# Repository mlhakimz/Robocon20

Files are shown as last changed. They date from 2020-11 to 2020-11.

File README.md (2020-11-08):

# Robocon20
2 Co-op robots playing Rugby 7s based on Fiji's Robocon 2020 theme.

## Mechanical Design

PASS ROBOT

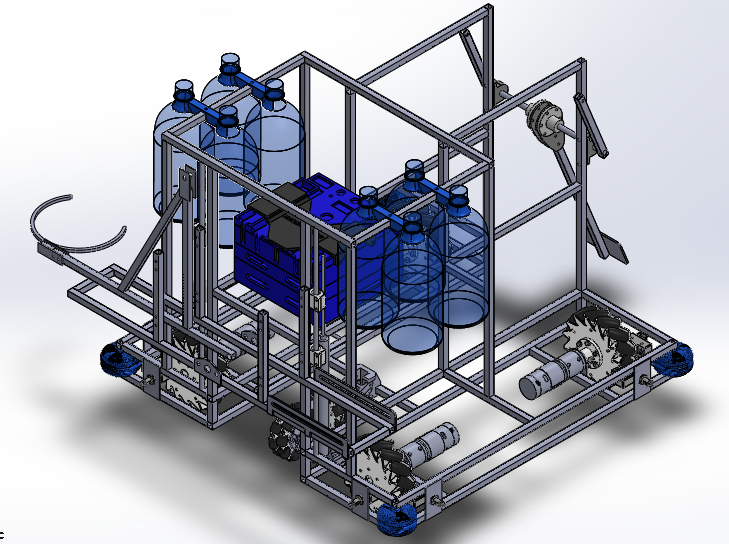
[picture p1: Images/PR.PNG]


TRY ROBOT

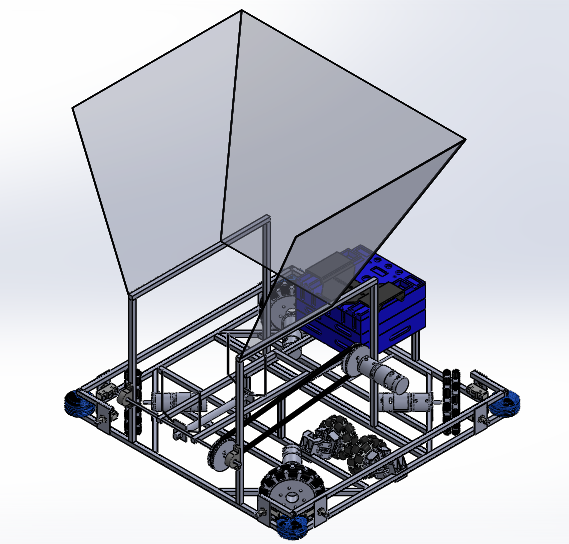
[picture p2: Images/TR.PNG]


## Electronics Design

PCB BOARD

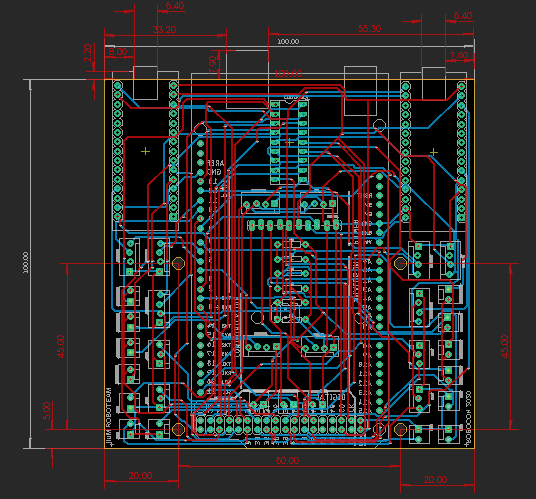
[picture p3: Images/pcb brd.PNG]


PCB SCHEMATIC

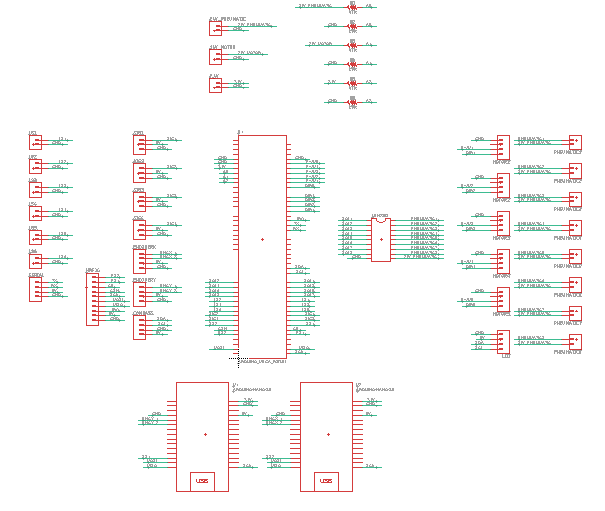
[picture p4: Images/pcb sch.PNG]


ARDUINO MEGA CONNECTIONS

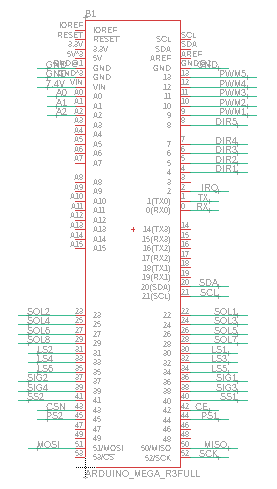
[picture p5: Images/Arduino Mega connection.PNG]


ARDUINO NANO CONNECTIONS

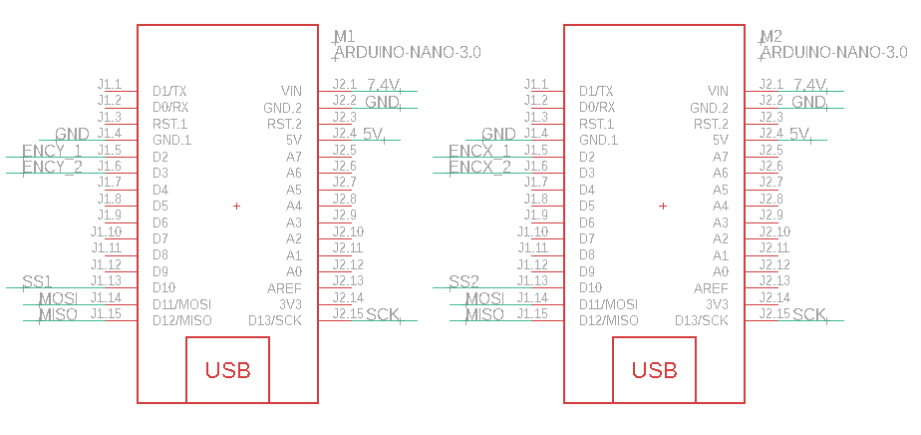
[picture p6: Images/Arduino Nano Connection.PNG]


INPUT PORTS

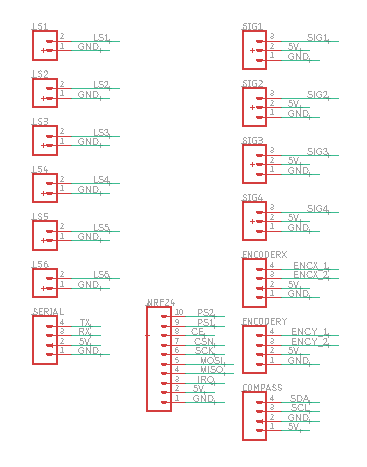
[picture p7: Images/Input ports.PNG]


OUTPUT PORTS

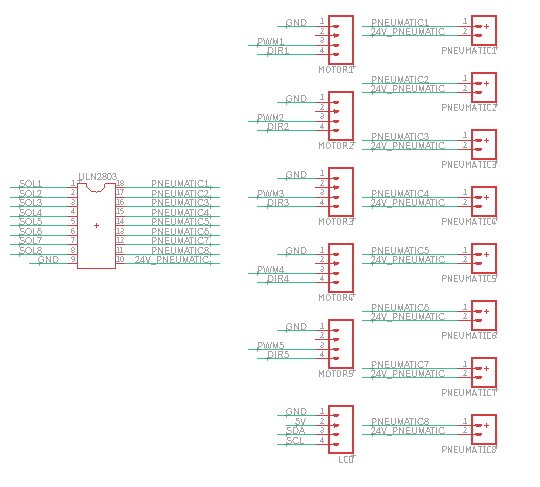
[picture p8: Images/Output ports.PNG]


VOLTMETER CONNECTION

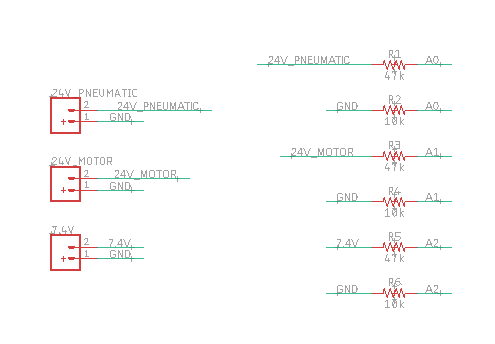
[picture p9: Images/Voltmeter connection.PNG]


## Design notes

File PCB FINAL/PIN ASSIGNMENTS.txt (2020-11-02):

2     - IRQ
4-8   - DIR
9-13  - PWM
20-21 - SDA SCL
22-29 - SOL (PNEUMATIC)
30-35 - LIMIT SWITCH
36-39 - DIGITAL INPUT (IR SENSOR)
50-52 - MISO MOSI SCK
40-41 - SLAVE SELECT
42-43 - CE CSN
A0-A2 - VOLTMETER

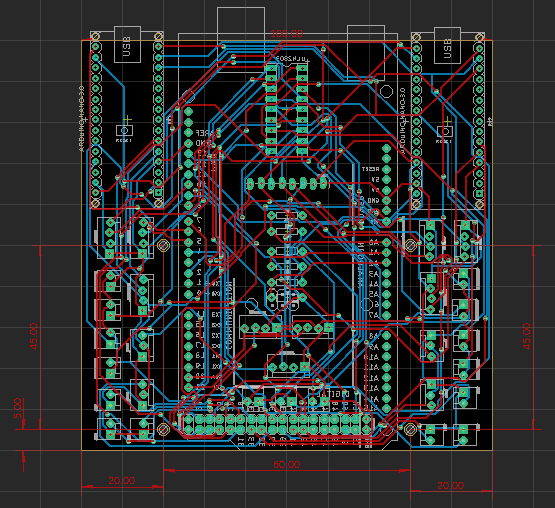
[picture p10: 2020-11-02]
PCB FINAL/PCB FINAL.PNG

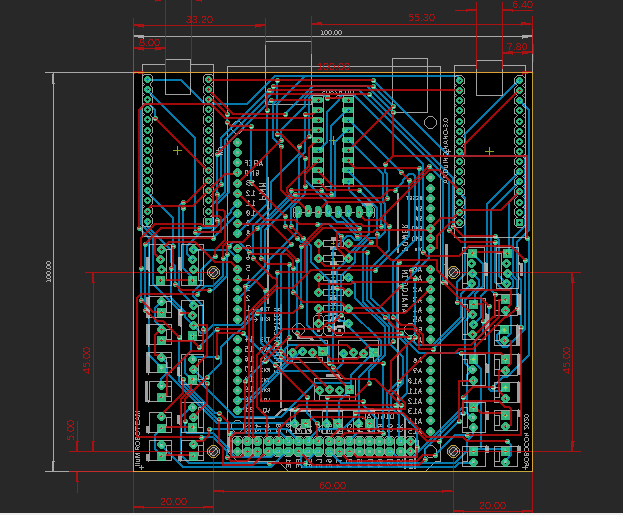
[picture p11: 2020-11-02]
PCB FINAL/PCB UPDATED.PNG

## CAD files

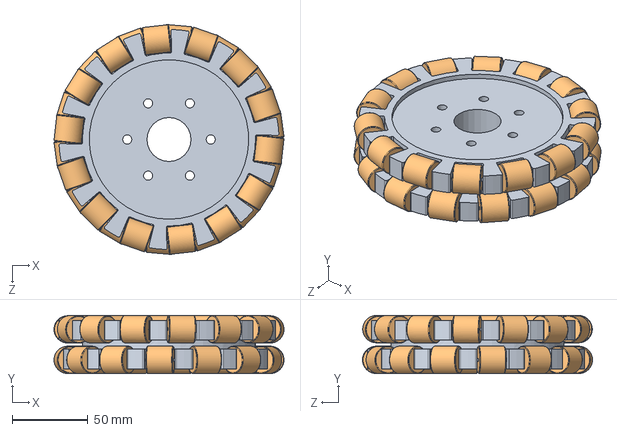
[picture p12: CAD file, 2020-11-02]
TR v2/Omni Wheel 152mm.SLDASM
151.5 x 38.3 x 151.6 mm
WHEEL x 28

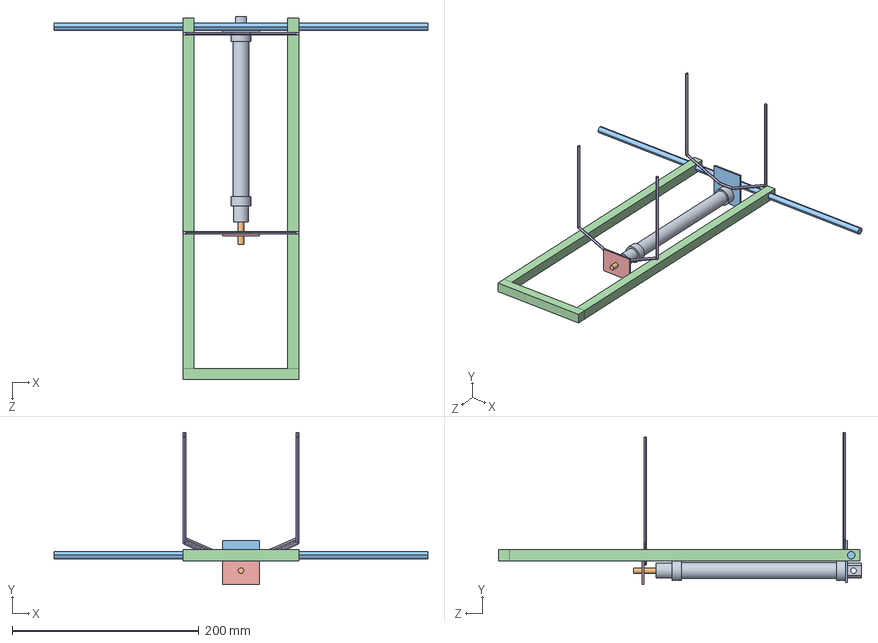
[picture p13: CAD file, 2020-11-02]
TR v2/try_mech.SLDASM
400.0 x 163.0 x 388.7 mm
Pneumatic_Body_125
Pneumatic_Rod_125
Rod_300
Platform_Receive
Plate_Var_Grip
Grip_V2 x 2

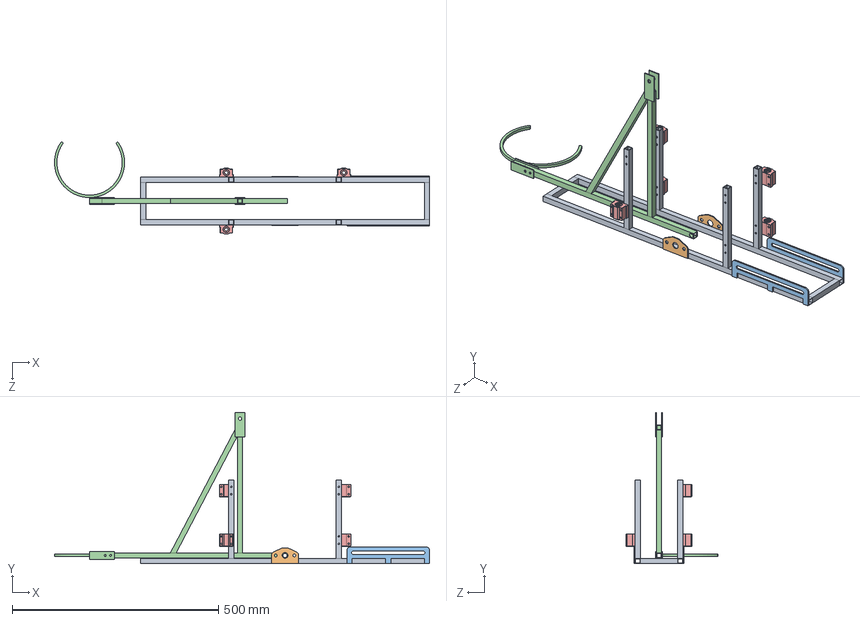
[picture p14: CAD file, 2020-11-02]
PR/Passing Mechanism.SLDASM
908.6 x 366.1 x 222.6 mm
Passing Mechanism Base v2
Bearing Plate x 2
Pneumatic Bottom Slot x 2
Throwing Arm
Linear Bearing 8mm ID x 4

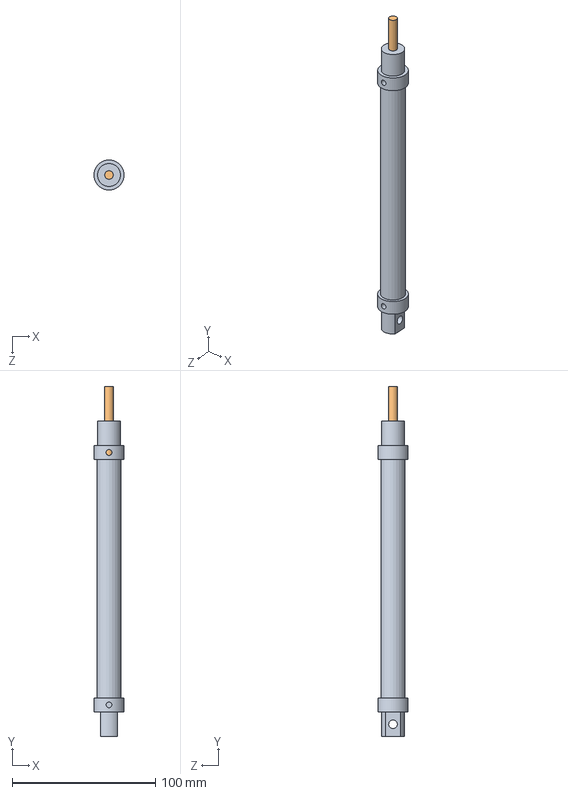
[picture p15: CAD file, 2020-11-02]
TR v2/Pneumatic_125.SLDASM
21.0 x 244.0 x 21.0 mm
Pneumatic_Body_125
Pneumatic_Rod_125

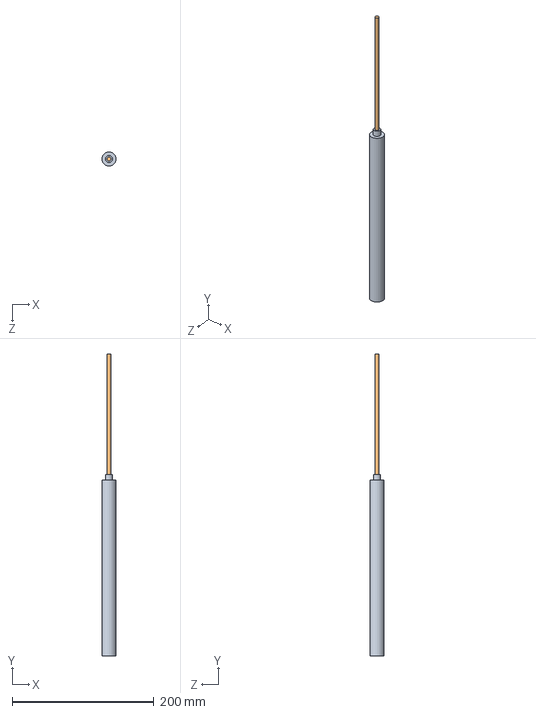
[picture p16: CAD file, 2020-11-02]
PR/Pneumatic16x200.SLDASM
20.0 x 426.1 x 20.0 mm
Pneumatic16x200 body
Pneumatic16x200 piston

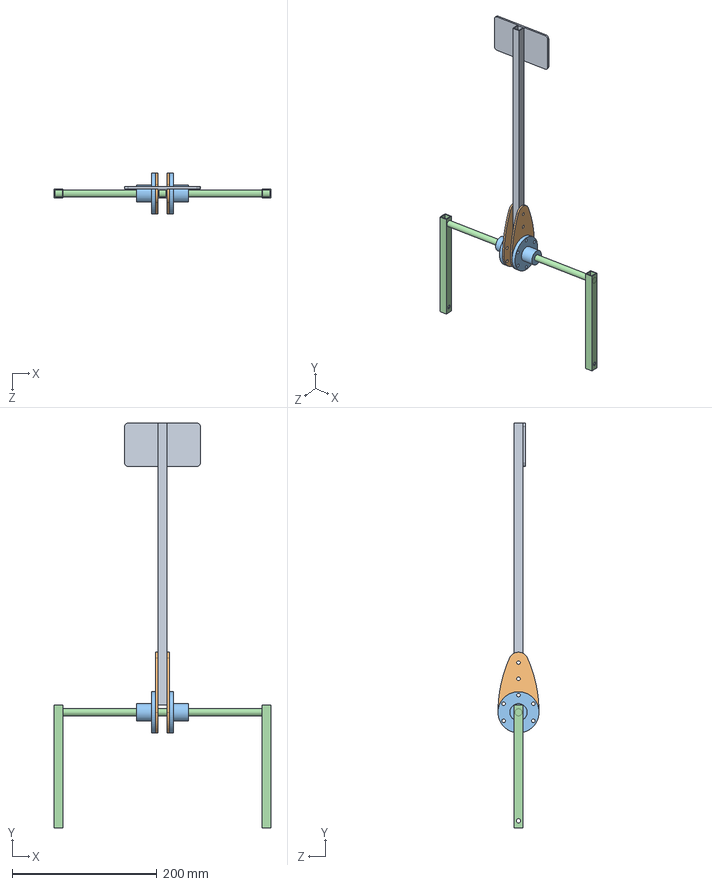
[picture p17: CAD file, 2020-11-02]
PR/Kicking Mechanism.SLDASM
300.0 x 560.0 x 56.8 mm
Kicking Leg
Coupler kicking 10mm x 2
Coupler 10mm x 2
Shaft 10mm diameter 300mm length

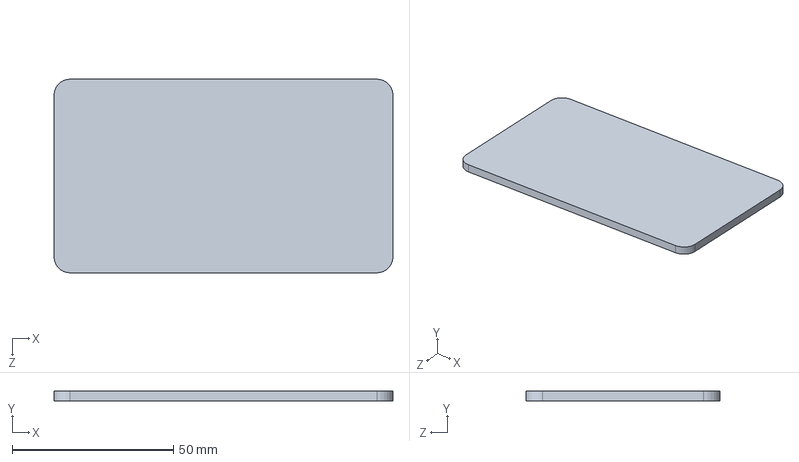
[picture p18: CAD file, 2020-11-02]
PR/Kicking Plate.SLDPRT
105.0 x 3.00 x 60.0 mm

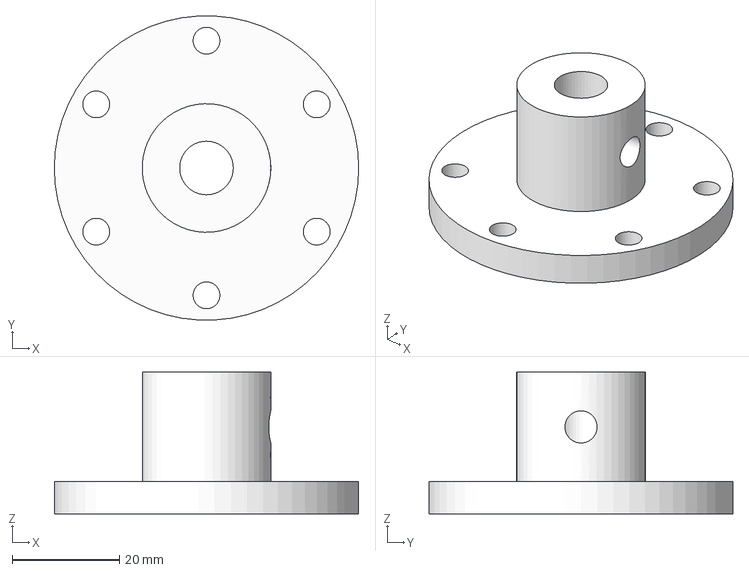
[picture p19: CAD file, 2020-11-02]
PR/Coupler 10mm.step
56.8 x 56.7 x 26.4 mm

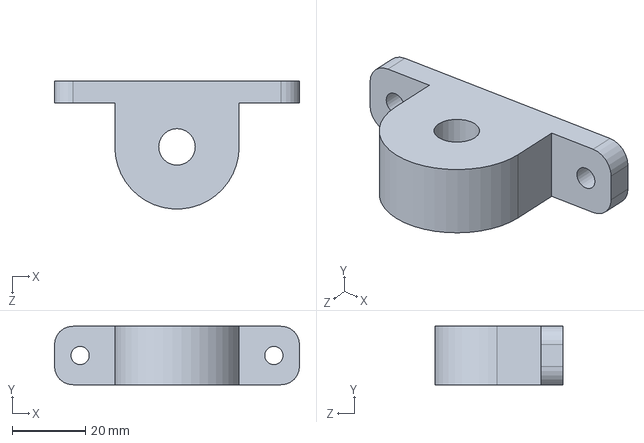
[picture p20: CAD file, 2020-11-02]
PR/Pillow Block Bearing 10mm.SLDPRT
67.0 x 16.0 x 35.0 mm

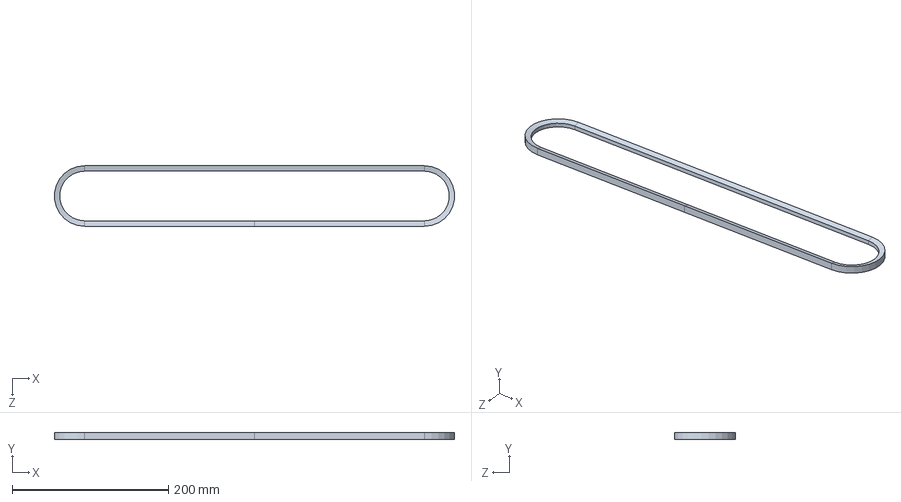
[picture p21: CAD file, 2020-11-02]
TR v2/v belt.SLDPRT
512.3 x 8.75 x 77.5 mm

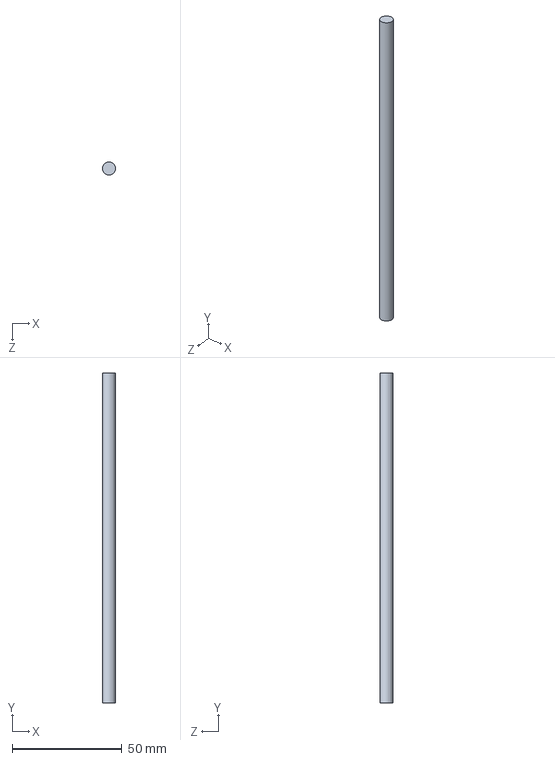
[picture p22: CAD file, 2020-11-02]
TR v2/Pneumatic_Rod_125.SLDPRT
6.00 x 150.0 x 6.00 mm

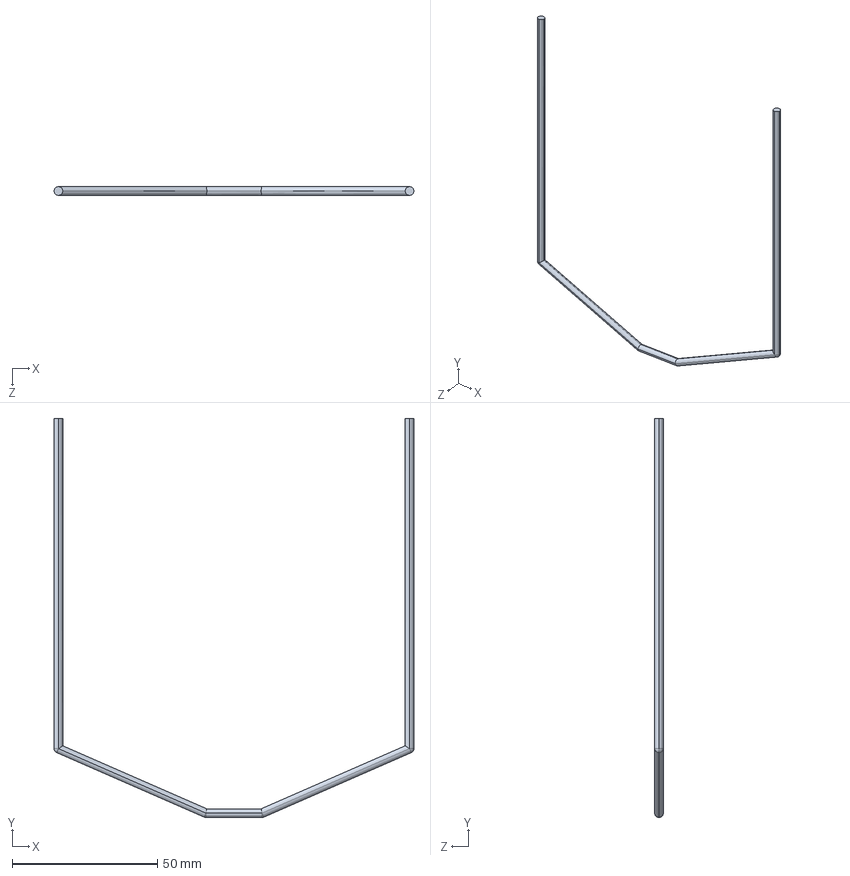
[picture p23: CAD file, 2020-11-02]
TR v2/Grip_V2.SLDPRT
124.0 x 137.5 x 3.00 mm

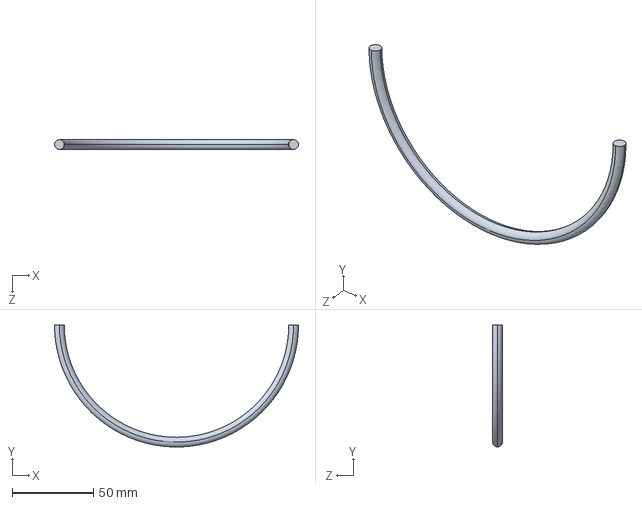
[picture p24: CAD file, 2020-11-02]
TR v2/U_Griper.SLDPRT
150.0 x 74.9 x 6.00 mm

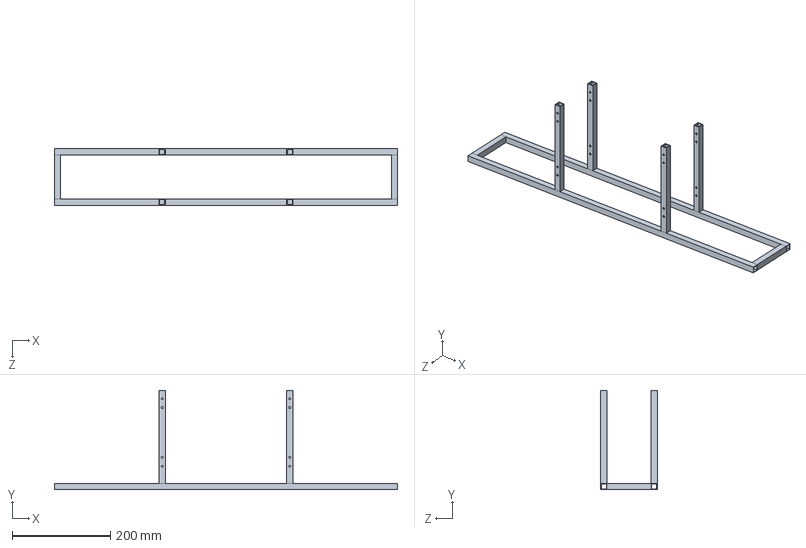
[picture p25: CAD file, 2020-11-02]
PR/Passing Mechanism Base v2.SLDPRT
700.0 x 202.7 x 115.4 mm

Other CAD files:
PR/Mecanum Wheel 6in.sldprt
TR v2/Part4.sldprt
PR/_X_CA_X_EE_X_ED_X_F6_X_E5_X_E2_X_E8_X_EA GQ21-B(Z-15GQ2_2-B) - _X_F8_X_E0_X_E9_X_E1_X_E0_00.sldprt
PR/Coupler kicking 10mm.SLDPRT
PR/4 inch onmiwheel roller.sldprt
PR/90348A024.sldprt
PR/9338T51.sldprt
PR/93625A200.sldprt
PR/Base PR.SLDPRT
PR/Bearing Plate.SLDPRT
PR/Coupler 10mm v3.step
PR/Coupler 10mm.SLDPRT
PR/Kicking Leg.SLDPRT
PR/Linear Bearing 8mm ID.SLDASM
PR/Linear Bearing 8mm ID.SLDPRT
PR/Linear Bearing 8mm ID.step
PR/Passing Mechanism Base.SLDPRT
PR/Pneumatic Bottom Slot.SLDPRT
PR/Pneumatic16x200 body.SLDPRT
PR/Pneumatic16x200 piston.SLDPRT
PR/Shaft 10mm diameter 300mm length.SLDPRT
PR/Throwing Arm.SLDPRT
PR/_X_CA_X_EE_X_ED_X_F6_X_E5_X_E2_X_E8_X_EA GQ21-B(Z-15GQ2_2-B) - _X_E3_X_E0_X_E9_X_EA_X_E0_00.sldprt
PR/_X_CA_X_EE_X_ED_X_F6_X_E5_X_E2_X_E8_X_EA GQ21-B(Z-15GQ2_2-B)_GQ22-B.sldprt
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

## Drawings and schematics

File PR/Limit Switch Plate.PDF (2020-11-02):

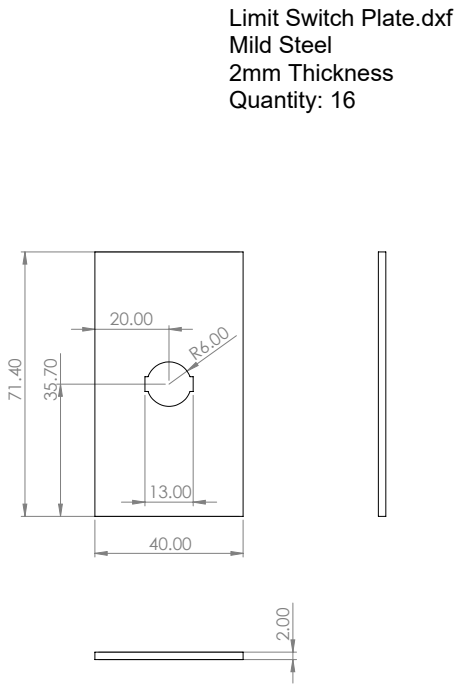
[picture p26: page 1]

Limit Switch Plate.dxf
Mild Steel
2mm Thickness
Quantity: 16

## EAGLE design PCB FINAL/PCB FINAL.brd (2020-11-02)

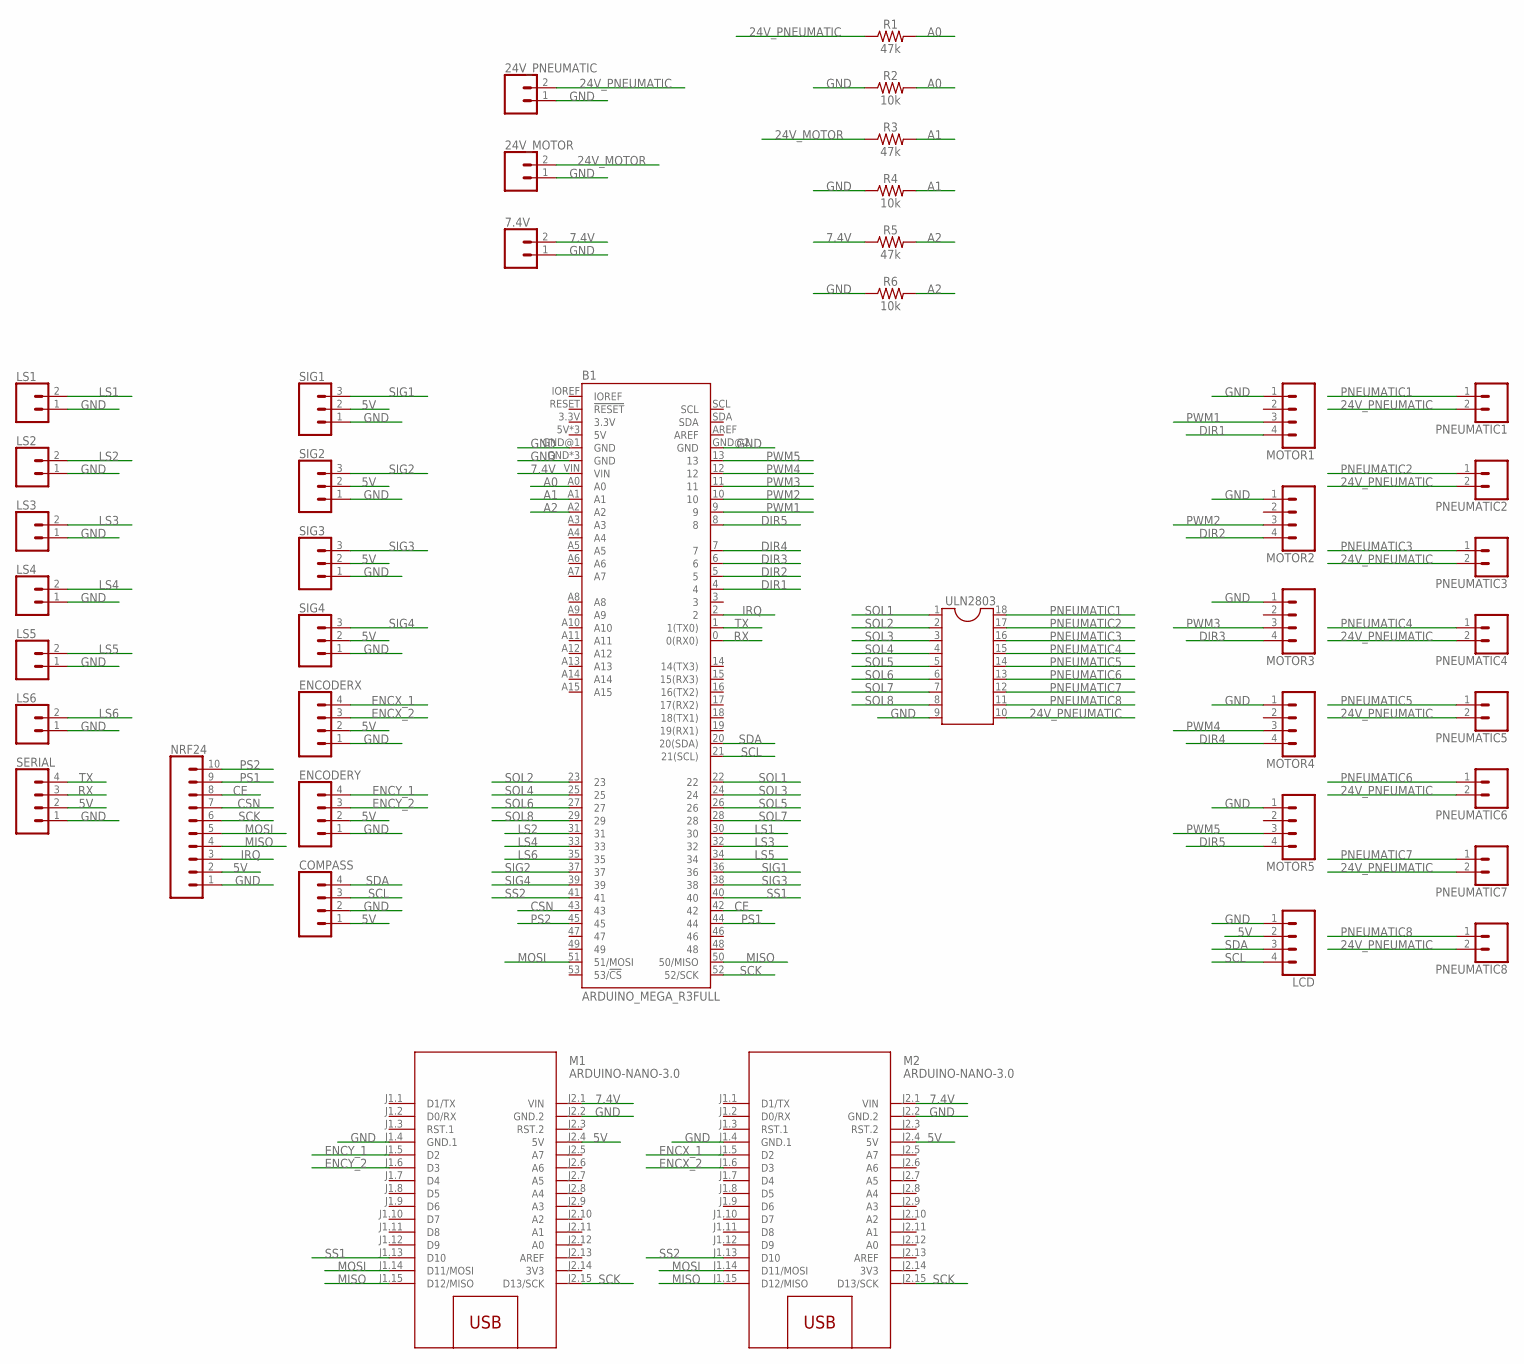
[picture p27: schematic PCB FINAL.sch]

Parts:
7.4V, 24V_MOTOR, 24V_PNEUMATIC: CONN_02POLAR_LOCK; MOLEX-1X2_LOCK
B1: ARDUINO_MEGA_R3FULL; ARDUINO_MEGA_NO_SILK
COMPASS: CONN_04POLAR_LOCK; MOLEX-1X4_LOCK
ENCODERX: CONN_04POLAR_LOCK; MOLEX-1X4_LOCK
ENCODERY: CONN_04POLAR_LOCK; MOLEX-1X4_LOCK
LCD: CONN_04POLAR_LOCK; MOLEX-1X4_LOCK
LS1, LS2, LS3, LS4, LS5, LS6: CONN_02POLAR_LOCK; MOLEX-1X2_LOCK
M1, M2: ARDUINO-NANO-3.0
MOTOR1, MOTOR2, MOTOR3, MOTOR4, MOTOR5: CONN_04POLAR_LOCK; MOLEX-1X4_LOCK
NRF24: CONN_10LOCK_LONGPADS; 1X10_LOCK_LONGPADS
PNEUMATIC1, PNEUMATIC2, PNEUMATIC3, PNEUMATIC4, PNEUMATIC5, PNEUMATIC6, PNEUMATIC7, PNEUMATIC8: CONN_02POLAR_LOCK; MOLEX-1X2_LOCK
R1, R3, R5: 47k; AXIAL-0.3
R2, R4, R6: 10k; AXIAL-0.3
SERIAL: CONN_04POLAR_LOCK; MOLEX-1X4_LOCK
SIG1, SIG2, SIG3, SIG4: CONN_03POLAR_LOCK; MOLEX-1X3_LOCK
ULN2803: DIL18S; SOCKET-18

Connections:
3V3: M1.J2.14 (3V3), M2.J2.14 (3V3)
5V: COMPASS.1, ENCODERX.2, ENCODERY.2, LCD.2, M1.J2.4 (5V), M2.J2.4 (5V), NRF24.2, SERIAL.2, SIG1.2, SIG2.2, SIG3.2, SIG4.2
7.4V: 7.4V.2, B1.VIN, M1.J2.1 (VIN), M2.J2.1 (VIN), R5.P$1 (1)
24V_MOTOR: 24V_MOTOR.2, R3.P$1 (1)
24V_PNEUMATIC: 24V_PNEUMATIC.2, PNEUMATIC1.2, PNEUMATIC2.2, PNEUMATIC3.2, PNEUMATIC4.2, PNEUMATIC5.2, PNEUMATIC6.2, PNEUMATIC7.2, PNEUMATIC8.2, R1.P$1 (1), ULN2803.10
A0: B1.A0, R1.P$2 (2), R2.P$2 (2)
A1: B1.A1, R3.P$2 (2), R4.P$2 (2)
A2: B1.A2, R5.P$2 (2), R6.P$2 (2)
CE: B1.42, NRF24.8
CSN: B1.43, NRF24.7
DIR1: B1.4, MOTOR1.4
DIR2: B1.5, MOTOR2.4
DIR3: B1.6, MOTOR3.4
DIR4: B1.7, MOTOR4.4
DIR5: B1.8, MOTOR5.4
ENCX_1: ENCODERX.4, M2.J1.5 (D2)
ENCX_2: ENCODERX.3, M2.J1.6 (D3)
ENCY_1: ENCODERY.4, M1.J1.5 (D2)
ENCY_2: ENCODERY.3, M1.J1.6 (D3)
GND: 7.4V.1, 24V_MOTOR.1, 24V_PNEUMATIC.1, B1.GND, B1.GND@1 (GND), B1.GND@2 (GND), B1.GND@3 (GND), B1.GND@4 (GND), COMPASS.2, ENCODERX.1, ENCODERY.1, LCD.1, LS1.1, LS2.1, LS3.1, LS4.1, LS5.1, LS6.1, M1.J1.4 (GND.1), M1.J2.2 (GND.2), M2.J1.4 (GND.1), M2.J2.2 (GND.2), MOTOR1.1, MOTOR2.1, MOTOR3.1, MOTOR4.1, MOTOR5.1, NRF24.1, R2.P$1 (1), R4.P$1 (1), R6.P$1 (1), SERIAL.1, SIG1.1, SIG2.1, SIG3.1, SIG4.1, ULN2803.9
IRQ: B1.2, NRF24.3
LS1: B1.30, LS1.2
LS2: B1.31, LS2.2
LS3: B1.32, LS3.2
LS4: B1.33, LS4.2
LS5: B1.34, LS5.2
LS6: B1.35, LS6.2
MISO: B1.50 (50/MISO), M1.J1.15 (D12/MISO), M2.J1.15 (D12/MISO), NRF24.4
MOSI: B1.51 (51/MOSI), M1.J1.14 (D11/MOSI), M2.J1.14 (D11/MOSI), NRF24.5
PNEUMATIC1: PNEUMATIC1.1, ULN2803.18
PNEUMATIC2: PNEUMATIC2.1, ULN2803.17
PNEUMATIC3: PNEUMATIC3.1, ULN2803.16
PNEUMATIC4: PNEUMATIC4.1, ULN2803.15
PNEUMATIC5: PNEUMATIC5.1, ULN2803.14
PNEUMATIC6: PNEUMATIC6.1, ULN2803.13
PNEUMATIC7: PNEUMATIC7.1, ULN2803.12
PNEUMATIC8: PNEUMATIC8.1, ULN2803.11
PS1: B1.44, NRF24.9
PS2: B1.45, NRF24.10
PWM1: B1.9, MOTOR1.3
PWM2: B1.10, MOTOR2.3
PWM3: B1.11, MOTOR3.3
PWM4: B1.12, MOTOR4.3
PWM5: B1.13, MOTOR5.3
RX: B1.0 (0(RX0)), SERIAL.3
SCK: B1.52 (52/SCK), M1.J2.15 (D13/SCK), M2.J2.15 (D13/SCK), NRF24.6
SCL: B1.21 (21(SCL)), COMPASS.3, LCD.4
SDA: B1.20 (20(SDA)), COMPASS.4, LCD.3
SIG1: B1.36, SIG1.3
SIG2: B1.37, SIG2.3
SIG3: B1.38, SIG3.3
SIG4: B1.39, SIG4.3
SOL1: B1.22, ULN2803.1
SOL2: B1.23, ULN2803.2
SOL3: B1.24, ULN2803.3
SOL4: B1.25, ULN2803.4
SOL5: B1.26, ULN2803.5
SOL6: B1.27, ULN2803.6
SOL7: B1.28, ULN2803.7
SOL8: B1.29, ULN2803.8
SS1: B1.40, M1.J1.13 (D10)
SS2: B1.41, M2.J1.13 (D10)
TX: B1.1 (1(TX0)), SERIAL.4

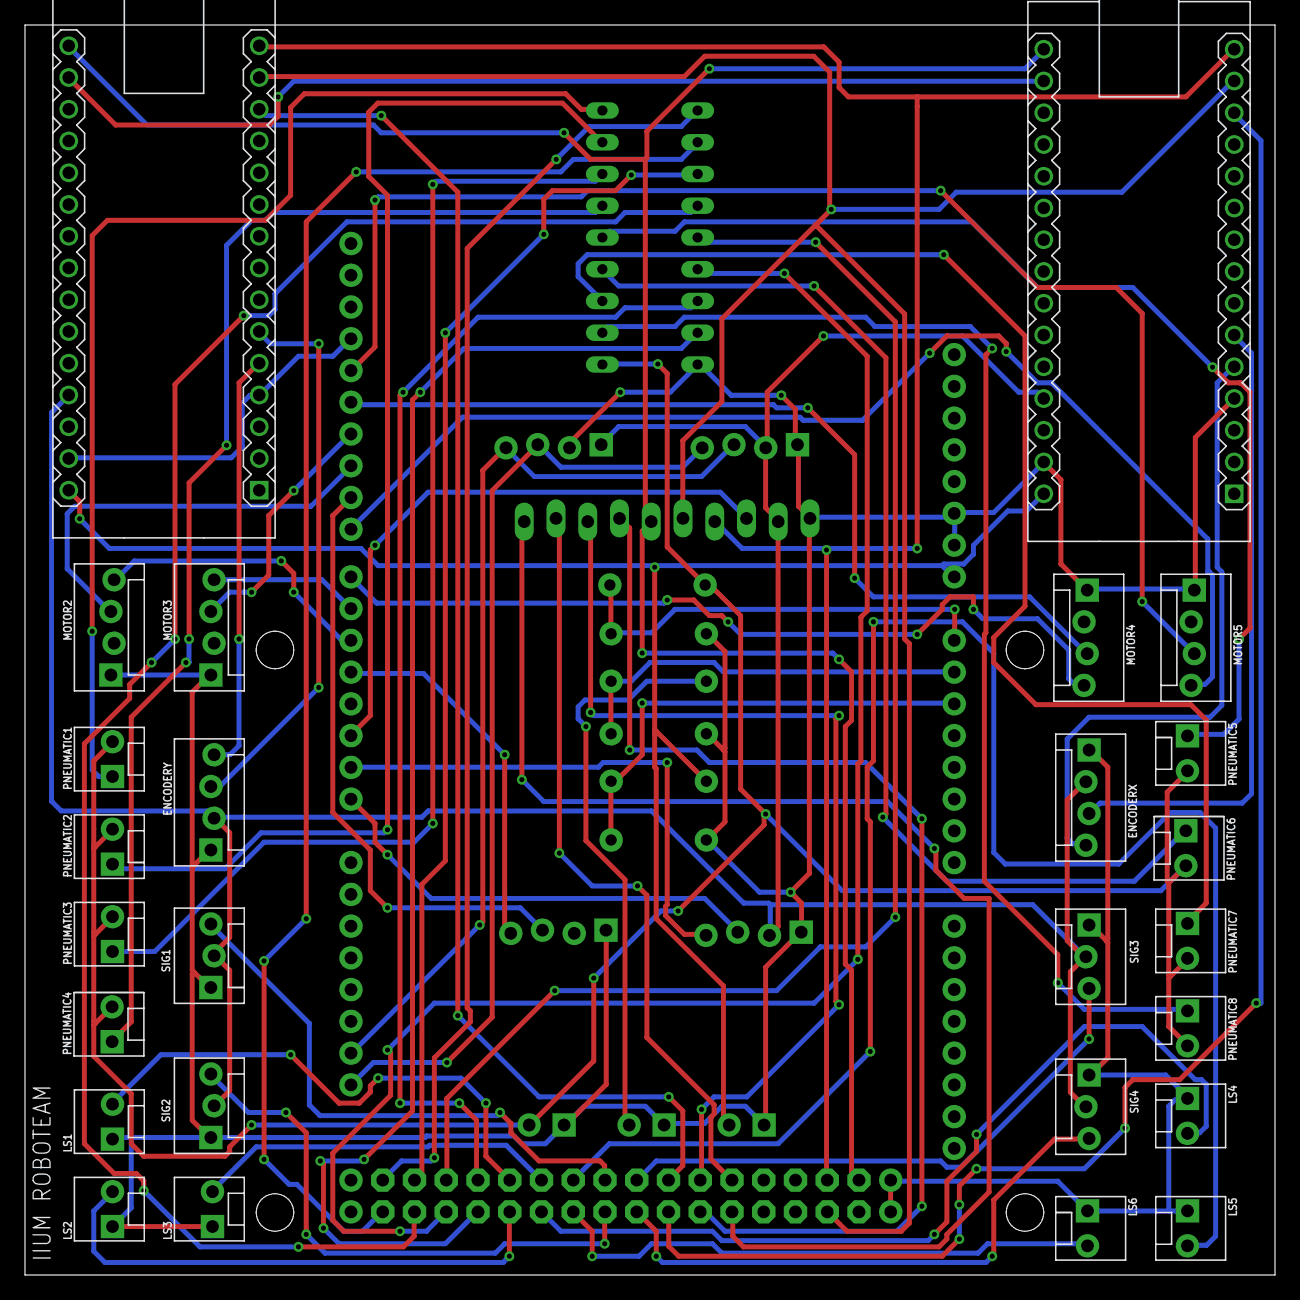
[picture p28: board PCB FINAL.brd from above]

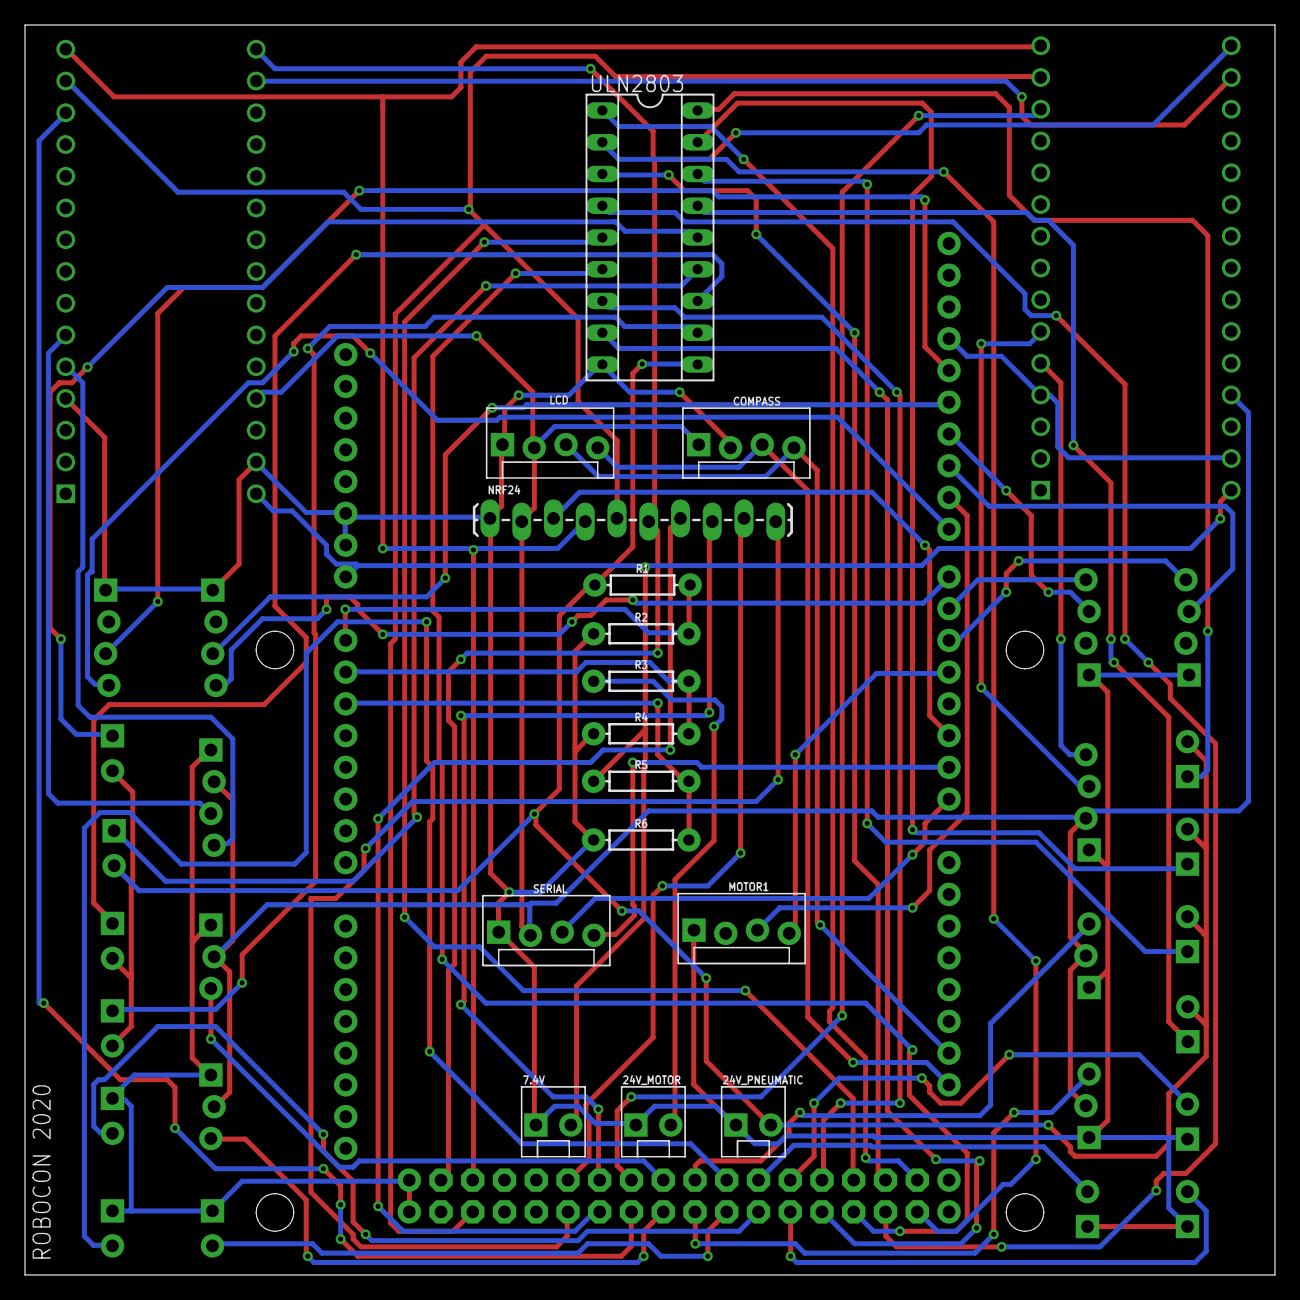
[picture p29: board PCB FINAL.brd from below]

Board: 2 copper layers, 100.0 x 100.0 mm, 42 parts (16 on the bottom side), 63 nets.

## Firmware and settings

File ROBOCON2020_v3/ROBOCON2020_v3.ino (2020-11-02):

//**********************LIBRARY************************//
#include <Wire.h>
#include <LiquidCrystal_I2C.h>
#include <MPU6050_tockn.h>
#include <SPI.h>
#include <PS2X_lib.h>

//**********************TIMINGS************************//
unsigned long currentmillis;
unsigned long prevmillis = 0;
int inputrate = 50;
int lcdratemultiplier = 3;
int lcdcount = 0;
float elapsedtime = (float)inputrate / 1000;

//***********************INPUTS************************//
//Voltmeter
float multiplier;
int VOLTMETER0 = A0;
int VOLTMETER1 = A1;
int VOLTMETER2 = A2;
int volt0;
int volt1;
int volt2;

//PS2
PS2X ps2x;
int error = 0;
int mode = 0;

//ENCODER
const int SS1 = 40;
const int SS2 = 41;
int16_t X = 0;
int16_t Y = 0;
int8_t PosX = 0;
int8_t PosY = 0;

//MPU
MPU6050 mpu6050(Wire);
float heading = 0;
float headingDegrees = 0;
float offsetDegrees = 0;
float driftDegrees = 0;
float driftrate = 0.02;
int C = 0;

//LIMIT SWITCH
const int LS1 = 30;
const int LS2 = 31;
const int LS3 = 32;
const int LS4 = 33;
const int LS5 = 34;
const int LS6 = 35;
int ls1 = LOW;
int ls2 = LOW;
int ls3 = LOW;
int ls4 = LOW;
int ls5 = LOW;
int ls6 = LOW;

//IR SENSOR
const int IR1 = 36;
const int IR2 = 37;
const int IR3 = 38;
const int IR4 = 39;
int ir1;

//*******************************OUTPUT********************************//
//MOTORS
int PWMFRL = 12;
int PWMFRR = 11;
int PWMBCL = 13;
int PWMBCR = 10;
int PWMKIK = 9;
int DIRFRL = 7;
int DIRFRR = 6;
int DIRBCL = 8;
int DIRBCR = 5;
int DIRKIK = 4;
int pwmfrr;
int pwmbcr;
int pwmfrl;
int pwmbcl;
int maxSpeed = 150;
int stickY = 0, stickX = 0, stickW = 0;
bool slowMove = false;
int kickflag = 0;

//PNEUMATICS
const int PN1 = 22;
const int PN2 = 23;
const int PN3 = 24;
const int PN4 = 25;
const int PN5 = 26;
const int PN6 = 27;
const int PN7 = 28;
const int PN8 = 29;
int countPN7 = 0;
int countPN8 = 0;
int isPN7 = LOW;
int isPN8 = LOW;

//LCD
LiquidCrystal_I2C lcd = LiquidCrystal_I2C(0x27, 16, 2);

//PID & AUTO
int adjust;
float kfrr = 0.8;
float kfrl = 0.83;
float kbcr = 0.8;
float kbcl = 0.8;
float Cp = 2.5;
float Ci = 0.06;
float Cd = 0.1;
float Xp = 0.5;
float Xi = 0;
float Xd = 0;
float Yp = 0.5;
float Yi = 0;
float Yd = 0;
float proportional[] = {0, Xp, Yp, Cp};
float integral[] = {0, Xi, Yi, Ci};
float derivative[] = {0, Xd, Yd, Cd};
float setpointX = 0;
float setpointY = 0;
float setpointC = 0;
float lasterrorX = 0;
float lasterrorY = 0;
float lasterrorC = 0;
float errorX = 0;
float errorY = 0;
float errorC = 0;
float errorXi = 0;
float errorYi = 0;
float errorCi = 0;
float errorXd = 0;
float errorYd = 0;
float errorCd = 0;
float XPID = 0;
float YPID = 0;
float CPID = 0;
int field = 0; //0 BLUE, 1 RED
int state = 0; //0 NULL, 1 READY, 2 WAIT
int task = 0;
int prevtask = 0;
char *FIELD[] = {"FIELD", "BLUE", "RED"};
char *STATE[] = {" ", "READY", "WAIT"};
char *ADJUST[] = {"ADJUST", "X", "Y", "C"};
int firstenter = 0;

void setup() {
  //    Serial.begin(9600);

  //PS2
  error = ps2x.config_gamepad(43, 44, 42, 45, false, false); //GamePad(clock, command, attention, data, Pressures?, Rumble?)
  delay(500);

  //MPU
  mpu6050.begin();
  mpu6050.calcGyroOffsets(true);
  delay(500);
  //ENCODER
  pinMode (SS1, OUTPUT);
  pinMode (SS2, OUTPUT);
  SPI.begin();
  SPI.setClockDivider(SPI_CLOCK_DIV8);
  digitalWrite(SS1, HIGH);
  digitalWrite(SS2, HIGH);
  delay(500);
  //LIMIT SWITCH
  pinMode(LS1, INPUT_PULLUP);
  pinMode(LS2, INPUT_PULLUP);
  pinMode(LS3, INPUT_PULLUP);
  pinMode(LS4, INPUT_PULLUP);
  pinMode(LS5, INPUT_PULLUP);
  pinMode(LS6, INPUT_PULLUP);
  delay(500);
  //MOTOR
  pinMode(PWMFRL, OUTPUT);
  pinMode(PWMFRR, OUTPUT);
  pinMode(PWMBCL, OUTPUT);
  pinMode(PWMBCR, OUTPUT);
  pinMode(PWMKIK, OUTPUT);
  pinMode(DIRFRL, OUTPUT);
  pinMode(DIRFRR, OUTPUT);
  pinMode(DIRBCL, OUTPUT);
  pinMode(DIRBCR, OUTPUT);
  pinMode(DIRKIK, OUTPUT);
  delay(500);
  //PNEUMATIC
  pinMode(PN1, OUTPUT);
  pinMode(PN2, OUTPUT);
  pinMode(PN3, OUTPUT);
  pinMode(PN4, OUTPUT);
  pinMode(PN5, OUTPUT);
  pinMode(PN6, OUTPUT);
  pinMode(PN7, OUTPUT);
  pinMode(PN8, OUTPUT);
  delay(500);
  //IR SENSOR
  pinMode(IR1, INPUT);

  //LASER
  pinMode(IR2, OUTPUT);
  digitalWrite(IR2, HIGH);

  //LCD
  lcd.init();
  lcd.backlight();
}

void loop() {
  currentmillis = millis();
  if (currentmillis - prevmillis >= inputrate) {
    MainMenu();
    ReadInput();
    prevmillis = currentmillis;
  }
}

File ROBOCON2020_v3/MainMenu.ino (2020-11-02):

void MainMenu() {
  if (mode == 0) {
    MoveRobot(0, 0, 0);
//    analogWrite(PWMKIK, 0);
    if (lcdcount > lcdratemultiplier) {
      lcd.clear();
      lcd.setCursor(0, 0);
      lcd.print("Q: MAN");
      lcd.setCursor(8, 0);
      lcd.print("T: PID");
      lcd.setCursor(0, 1);
      lcd.print("O: AUTO");
      lcd.setCursor(8, 1);
      lcd.print("X: VAL");
      lcdcount = 0;
    }
    lcdcount++;

    if (ps2x.Button(PSB_SQUARE))
    {
      Manual();
      mode = 1;
    }

    if (ps2x.Button(PSB_TRIANGLE))
    {
      AdjustPID();
      mode = 2;
    }

    if (ps2x.Button(PSB_CIRCLE))
    {
      Auto();
      mode = 3;
    }

    if (ps2x.Button(PSB_CROSS))
    {
      Value();
      mode = 4;
    }
  }
  else if (mode == 1) {
    Manual();
  }
  else if (mode == 2) {
    AdjustPID();
  }
  else if (mode == 3) {
    Auto();
  }
  else if (mode == 4) {
    Value();
  }
  else {
    mode = 0;
  }
}

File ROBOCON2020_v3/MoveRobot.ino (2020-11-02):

void MoveRobot(int stickX, int stickY, int stickW) {
//  if(stickX !=0 || stickY != 0 || stickW != 0){
//    driftDegrees += driftrate;
//  }
  volt1 = analogRead(VOLTMETER1);
  multiplier = map(volt1, 720, 907, 1000, 791)/1000.0;

  int pwmfrr = 1 * (stickX - stickY + stickW);
  int pwmbcr = -1 * (stickX + stickY - stickW);
  int pwmfrl = -1 * (stickX + stickY + stickW);
  int pwmbcl = -1 * (stickX - stickY - stickW);

  digitalWrite(DIRFRL, determineDir(pwmfrl));   //Set motor direction
  digitalWrite(DIRFRR, determineDir(pwmfrr));
  digitalWrite(DIRBCL, determineDir(pwmbcl));
  digitalWrite(DIRBCR, determineDir(pwmbcr));

  pwmfrl = abs(pwmfrl);     //Set pwm value to positive
  if (pwmfrl > maxSpeed)    //Set motor maxSpeed
    pwmfrl = maxSpeed;

  pwmfrr = abs(pwmfrr);
  if (pwmfrr > maxSpeed)
    pwmfrr = maxSpeed;

  pwmbcl = abs(pwmbcl);
  if (pwmbcl > maxSpeed)
    pwmbcl = maxSpeed;

  pwmbcr = abs(pwmbcr);
  if (pwmbcr > maxSpeed)
    pwmbcr = maxSpeed;

  if (slowMove) {        //Motor move slow if R2 is pressed
    pwmfrl /= 4;
    pwmfrr /= 4;
    pwmbcl /= 4;
    pwmbcr /= 4;
  }
  //  Serial.print("FL: ");
  //  Serial.print(pwmfrl);
  //  Serial.print("   ");
  //  Serial.print("FR: ");
  //  Serial.print(pwmfrr);
  //  Serial.print("   ");
  //  Serial.print("BL: ");
  //  Serial.print(pwmbcl);
  //  Serial.print("   ");
  //  Serial.print("BR: ");
  //  Serial.print(pwmbcr);
  //  Serial.println("   ");
  analogWrite(PWMFRL, (kfrl * pwmfrl * multiplier));  //Set pwm value to motor
  analogWrite(PWMFRR, (kfrr * pwmfrr * multiplier));
  analogWrite(PWMBCL, (kbcl * pwmbcl * multiplier));
  analogWrite(PWMBCR, (kbcr * pwmbcr * multiplier));

}

int determineDir(int velocity) {  //Determine motor direction
  if (velocity >= 0)
    return HIGH;

  else
    return LOW;
}

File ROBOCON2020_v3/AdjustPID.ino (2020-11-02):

void AdjustPID() {
  if (ps2x.Button(PSB_START)) {
    mode = 0;
  }
  if (lcdcount > lcdratemultiplier) {
    if (adjust == 0) {
      lcd.clear();
      lcd.setCursor(0, 0);
      lcd.print(kfrl * 1000);
      lcd.setCursor(8, 0);
      lcd.print(kfrr * 1000);
      lcd.setCursor(0, 1);
      lcd.print(kbcl * 1000);
      lcd.setCursor(8, 1);
      lcd.print(kbcr * 1000);
    }
    else{
    lcd.clear();
    lcd.setCursor(0, 0);
    lcd.print(ADJUST[adjust]);
    lcd.setCursor(8, 0);
    lcd.print(proportional[adjust] * 1000);
    lcd.setCursor(0, 1);
    lcd.print(integral[adjust] * 1000);
    lcd.setCursor(8, 1);
    lcd.print(derivative[adjust] * 1000);
    lcdcount = 0;
    }
  }
  lcdcount++;

  if (ps2x.Button(PSB_TRIANGLE)) {
    adjust = 0;
  }

  if (ps2x.Button(PSB_CROSS)) {
    adjust = 1;
  }

  if (ps2x.Button(PSB_CIRCLE)) {
    adjust = 2;
  }

  if (ps2x.Button(PSB_SQUARE)) {
    adjust = 3;
  }

  if (ps2x.Button(PSB_R1) && ps2x.Button(PSB_PAD_UP)) {
    if (adjust == 0) {
      kbcr += 0.001;
    }
    else if (adjust == 1) {
      Xp += 0.001;
      proportional[adjust] = Xp;
    }
    else if (adjust == 2) {
      Yp += 0.001;
      proportional[adjust] = Yp;
    }
    else if (adjust == 3) {
      Cp += 0.001;
      proportional[adjust] = Cp;
    }
  }

  if (ps2x.Button(PSB_R1) && ps2x.Button(PSB_PAD_DOWN)) {
    if (adjust == 0) {
      kbcr -= 0.001;
    }
    else if (adjust == 1) {
      Xp -= 0.001;
      proportional[adjust] = Xp;
    }
    else if (adjust == 2) {
      Yp -= 0.001;
      proportional[adjust] = Yp;
    }
    else if (adjust == 3) {
      Cp -= 0.001;
      proportional[adjust] = Cp;
    }
  }

  if (ps2x.Button(PSB_R2) && ps2x.Button(PSB_PAD_UP)) {
    if (adjust == 0) {
      kfrr += 0.001;
    }
    else if (adjust == 1) {
      Xi += 0.001;
      integral[adjust] = Xi;
    }
    else if (adjust == 2) {
      Yi += 0.001;
      integral[adjust] = Yi;
    }
    else if (adjust == 3) {
      Ci += 0.001;
      integral[adjust] = Ci;
    }
  }

  if (ps2x.Button(PSB_R2) && ps2x.Button(PSB_PAD_DOWN)) {
    if (adjust == 0) {
      kfrr -= 0.001;
    }
    else if (adjust == 1) {
      Xi -= 0.001;
      integral[adjust] = Xi;
    }
    else if (adjust == 2) {
      Yi -= 0.001;
      integral[adjust] = Yi;
    }
    else if (adjust == 3) {
      Ci -= 0.001;
      integral[adjust] = Ci;
    }
  }

  if (ps2x.Button(PSB_L2) && ps2x.Button(PSB_PAD_UP)) {
    if (adjust == 0) {
      kfrl += 0.001;
    }
    else if (adjust == 1) {
      Xd += 0.001;
      derivative[adjust] = Xd;
    }
    else if (adjust == 2) {
      Yd += 0.001;
      derivative[adjust] = Yd;
    }
    else if (adjust == 3) {
      Cd += 0.001;
      derivative[adjust] = Cd;
    }
  }

  if (ps2x.Button(PSB_L2) && ps2x.Button(PSB_PAD_DOWN)) {
    if (adjust == 0) {
      kfrl -= 0.001;
    }
    else if (adjust == 1) {
      Xd -= 0.001;
      derivative[adjust] = Xd;
    }
    else if (adjust == 2) {
      Yd -= 0.001;
      derivative[adjust] = Yd;
    }
    else if (adjust == 3) {
      Cd -= 0.001;
      derivative[adjust] = Cd;
    }
  }
  
  if (ps2x.Button(PSB_L1) && ps2x.Button(PSB_PAD_UP)) {
    if (adjust == 0) {
      kbcl += 0.001;
    }
  }
  
  if (ps2x.Button(PSB_L1) && ps2x.Button(PSB_PAD_DOWN)) {
    if (adjust == 0) {
      kbcl -= 0.001;
    }
  }
}

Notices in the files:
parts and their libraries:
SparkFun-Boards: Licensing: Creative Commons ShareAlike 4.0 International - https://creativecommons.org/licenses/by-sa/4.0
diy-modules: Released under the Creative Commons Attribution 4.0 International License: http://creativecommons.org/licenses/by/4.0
